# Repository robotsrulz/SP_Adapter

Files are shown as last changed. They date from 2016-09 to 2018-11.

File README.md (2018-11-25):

Logitech G25/G27 pedals/shifter adapter
=======================================

The idea behind this project is to create open and inexpensive USB HID adapter for Logitech G25 / G27 pedals and shifters based on affordable components. Once you bought (or built) your new shiny and awesome direct drive steering wheel you no longer need your old but still working Logitech wheel. But it parts still can be used as standalone device.

I am aware that some shops already sell similar adapters. Unfortunately these devices are quite expensive and not open source. Also I want to practice a bit with STM32 programming :)

Hardware part is based on STM32F042 microcontroller(TSSOP20), Schematics folder contains Gerber files as well as DipTrace source files.

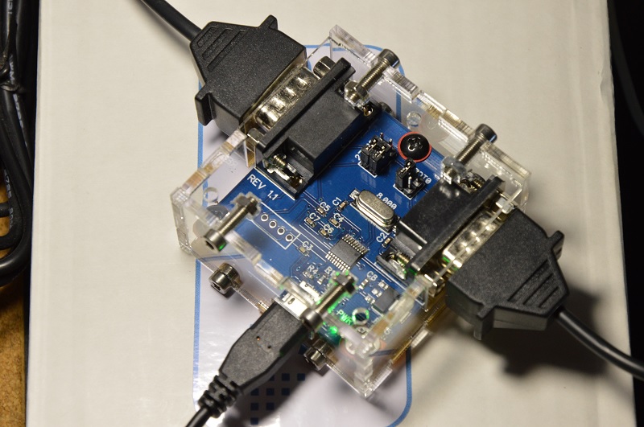
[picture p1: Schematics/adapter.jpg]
Adapter


New firmware for board revisions 1.0 and 1.1 with G25 sequential mode support:

 [hse-2.09a.dfu](binaries/hse-2.09a.dfu) 
 [SP_Profiler](binaries/SP_Profiler_209.exe) 
 
Previous firmware for board revisions 1.0 and 1.1:

 [hse-2.07a.dfu](binaries/hse-2.07a.dfu) 
 [SP_Profiler](binaries/SP_Profiler_1.2.exe) 
 
Firmware for STM32F103C8T6 "Blue Pill" development board:

 [bluepill-2.07.hex](https://github.com/robotsrulz/SP_Adapter/blob/stm32f103c8t6/binaries/bluepill-2.07.hex) 
 [SP_Profiler](binaries/SP_Profiler_1.2.exe) 
 
## Firmware update

1. Disconnect the device and open the case.
2. Place jumper BOOT0 to right position (assuming you're holding the board with USB connector down and DB9 connectors left and right. Normal position of BOOT0 jumper is left side).
3. Install STM DfuSe, download it here: https://goo.gl/JMUFBS (free registration required). Alternatively install it from my Google Drive: https://goo.gl/dp4XGH
4. Connect the board to computer, it should be detected as "STM device in DFU mode"
5. Download firmware .dfu file.
6. Run DfuSe, mark Verify checkbox, press Choose button, select firmware image, then press Upgrade, agree to the warning message.
7. When Progress bar turns blue firmware update is complete, disconnect the board, move jumper BOOT0 back to the left position, close the case, connect it to computer, the board should be detected as "Shifter/Pedals Adapter". Firmware update complete!

Calibration software (Windows x86):

 [SP_Profiler_1.2.exe](binaries/SP_Profiler_1.2.exe)
 
## Calibration procedure

1. Download and run SP_Profiler.exe.
2. The board should be detected as HID-device in the drop down menu, and red cross should be visible in the calibration area.
3. Press Read button, the blue lines should be visible.
4. The idea of shifter calibration is to match actual shifter X an Y potentiometer positions to gear detection zones, see illustration: calibration
You can move blue lines by altering numbers in corresponding edit fields, hit Update button after each edit. Then check if shifter positions are detected correctly. Once you satisfied how shifter detects selected gear press Update and close SP_Profiler, values are stored in adapter flash memory.

## Obtaining the board

PCB is available to order on [kitnic.it](https://kitnic.it/boards/github.com/robotsrulz/SP_Adapter/). I'm testing data for 1clickBOM Chrome plugin to order all parts from major component suppliers (Digikey, Mouser, RS, Newark, Farnell). I'm also selling a small amount of the boards assembled manually by myself, contact me if you want one.

## USB VID/PID

The board uses VID 0x1209 (InterBiometrics) / PID 0xF00D to identify itself, see [pid.codes](http://pid.codes/1209/F00D/) database.

## License

This project is licensed under the BSD License - see the [LICENSE](LICENSE) file for details

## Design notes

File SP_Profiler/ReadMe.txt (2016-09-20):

================================================================================
    БИБЛИОТЕКА MICROSOFT FOUNDATION CLASS. Обзор проекта SP_Profiler
===============================================================================

Это приложение SP_Profiler автоматически создано с помощью мастера приложений. Это приложение демонстрирует основные принципы использования классов Microsoft Foundation; оно также может использоваться в качестве основы для написания собственных приложений.

В этом файле представлена сводка содержимого всех файлов, входящих в состав приложения SP_Profiler.

SP_Profiler.vcxproj
    Это основной файл проекта VC++, создаваемый с помощью мастера приложений. Он содержит данные о версии языка Visual C++, использованной для создания файла, а также сведения о платформах, конфигурациях и функциях проекта, выбранных с помощью мастера приложений.

SP_Profiler.vcxproj.filters
    Это файл фильтров для проектов VC++, созданный с помощью мастера приложений. Он содержит сведения о сопоставлениях между файлами в вашем проекте и фильтрами. Эти сопоставления используются в среде IDE для группировки файлов с одинаковыми расширениями в одном узле (например CPP-файлы сопоставляются с фильтром "Исходные файлы").

SP_Profiler.h
    Это основной файл заголовка приложения.
    Он содержит прочие заголовки, относящиеся к проекту (включая Resource.h), а также объявляет класс приложения CSP_ProfilerApp.

SP_Profiler.cpp
    Это основной исходный файл приложения, в котором содержится класс приложения CSP_ProfilerApp.

SP_Profiler.rc
    Он представляет собой список всех ресурсов Microsoft Windows, используемых программой. В него включены значки, точечные рисунки и курсоры, хранящиеся в подкаталоге RES. Этот файл можно редактировать непосредственно в Microsoft Visual C++. Ресурсы проекта находятся в 1049.

res\SP_Profiler.ico
    Файл значка, используемый в качестве значка приложения. Этот значок включен с помощью основного файла ресурсов SP_Profiler.rc.

res\SP_Profiler.rc2
    Этот файл содержит ресурсы, которые нельзя редактировать в Microsoft Visual C++. В этот файл следует поместить все ресурсы, не редактируемые редактором ресурсов.

/////////////////////////////////////////////////////////////////////////////

Мастер приложений создает один класс диалогового окна:

SP_ProfilerDlg.h, SP_ProfilerDlg.cpp — диалоговое окно
    Эти файлы содержат класс CSP_ProfilerDlg. Этот класс определяет поведение главного диалогового окна приложения. Шаблон диалогового окна находится в файле SP_Profiler.rc, который можно изменять с помощью Microsoft Visual C++.

/////////////////////////////////////////////////////////////////////////////

Другие стандартные файлы:

StdAfx.h, StdAfx.cpp
    Эти файлы используются для построения файла предкомпилированного заголовка (PCH) с именем SP_Profiler.pch и файла предкомпилированных типов с именем StdAfx.obj.

Resource.h
    Это стандартный файл заголовка, в котором определяются новые идентификаторы ресурсов. Такой файл можно прочитать и обновить в Microsoft Visual C++.

SP_Profiler.manifest
	Файлы манифеста приложения используются операционной системой Windows XP для описания зависимости приложений от определенных версий параллельных сборок. Эти сведения используются загрузчиком для загрузки соответствующей сборки из кэша сборок или частным образом из приложения. Манифест приложения можно включить для распространения в качестве внешнего MANIFEST-файла, устанавливаемого в одной папке с исполняемым файлом приложения, или внедрить в исполняемый файл в виде ресурса.
/////////////////////////////////////////////////////////////////////////////

Прочие примечания.

С помощью комментариев «TODO:» в мастере приложений обозначаются фрагменты исходного кода, которые необходимо дополнить или изменить.

Если приложение использует MFC в общей библиотеке DLL, необходимо обеспечить распространение библиотек DLL MFC. Если в приложении используется язык, отличный от языка операционной системы, потребуется также обеспечить распространение соответствующих локализованных ресурсов mfc110XXX.DLL.
Дополнительные сведения о выполнении этих задач см. в разделе документации MSDN, посвященном распространению приложений Visual C++.

/////////////////////////////////////////////////////////////////////////////

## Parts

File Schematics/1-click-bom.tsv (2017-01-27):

References | Qty | Description | Manufacturer | MPN | Digikey | Mouser | RS | Newark | Farnell
25/27 | 1 |  |  | 90131-0123 | WM8121-ND | 538901310123 | 6703443 | 60H4442 | 2381222
BOOT0 | 1 |  |  | 90131-0122 | WM8120-ND | 538901310122 | 6703449 | 25M5898 | 1756986
C1-C2 | 2 | 22pF,0603 |  | C0603C220J1GACTU | 399-7874-2-ND | 80C0603C220J1G | 8015350 | 75R1532 | 1813429
C3-C4 | 2 | 100nF,0603 |  | C0603C104K5RACTU | 399-5089-2-ND | 80C0603C104K5R | 8015347 | 72J5992 | 1692286
C5 | 1 | 4.7uF,0603 |  | CL10A475KL8NRNC | 1276-6794-6-ND | 81GRM188R60J475ME9D | 6911155 | 62W5999 | 2211163
C6 | 1 | 10nF,0603 |  | C0603C103J5JAC7867 | 399-13384-1-ND | 810C1608X7R1H103K | 7882988 | 45Y5166 | 2470427
C7 | 1 | 1uF,0603 |  | GRM188R61H105KAALD | 490-10732-6-ND | 81GRM188R61H105KALD | 8467300 | 13T1194 | 1845736
C8 | 1 | 10uF,0603 |  | GRM188R6YA106MA73D | 490-13248-6-ND | 81GRM188R6YA106MA3D | 8151345 | 45Y5222 | 2470486
HC49SMD | 1 | 8.000 |  | AT-8.000MAGK-T | 887-1599-6-ND | 717AT8.000MAGKT | 6720340 | 76Y3930 | 2142539
LM1117-3.3 | 1 | REG1117-3.3 |  | LM1117MPX-3.3/NOPB | LM1117MPX-3.3/NOPBCT-ND | 926LM1117MPX3.3NOPB | 5358635 | 41K3450 | 1469051
PEDALS | 1 |  |  | 788750-1 | 788750-1-ND | 66720TQC47MYF | 1217389 | 01M3123 | 2294289
R1-R2 | 2 | 22R,0603 |  | RC0603JR-0722RL | 311-22GRCT-ND | 603RC0603JR0722RL | 8323168 | 68R0168 | 9233172
R3 | 1 | 100k,0603 |  | RC0603JR-07100KL | 311-100KGRCT-ND | 603RC0603JR07100KL | 6789673 | 68R0147 | 9233628
R4 | 1 | 4.7k 0603 |  | RC0603JR-074K7L | 311-4.7KGRCT-ND | 603RC0603JR0747KL | 7408877 | 68R0188 | 9233466
R5 | 1 | 360R 0603 |  | RC0603JR-07360RL | 311-360GRCT-ND | 603RC0603JR07360RL |  | 66R2746
PWR | 1 | LED 0603 |  | Q396-PS-35 | LG Q396-PS-35-ND | 720LGQ396A3964 |  | 86Y0826 | 2575345
SHIFTER | 1 |  |  | 787203-3 | A32089-ND | 57157472506 | 7981072 | 42K8789 | 1087695
ST-LINK | 1 |  |  | 640453-5 | A19341-ND | 5716404535 | 8640754 | 22C6367 | 588672
STM32F042F6P6 | 1 |  |  | STM32F042F6P | STM32F042F6P6-ND | 511STM32F042F6P6 | 8607501 | 42Y1015 | 2469549
USBMicroB | 1 |  |  | ZX62-B-5PA | H125270CT-ND | 798ZX62B5PA33 | 6850965 | 86P8793 | 1645325

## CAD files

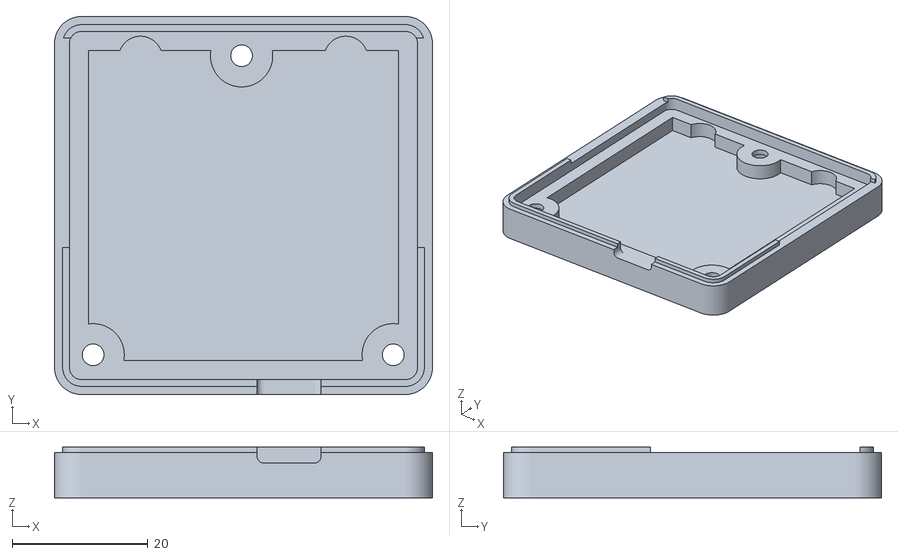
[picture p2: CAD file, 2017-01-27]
Schematics/Case_Bottom.stl
55.8 x 55.8 x 7.50

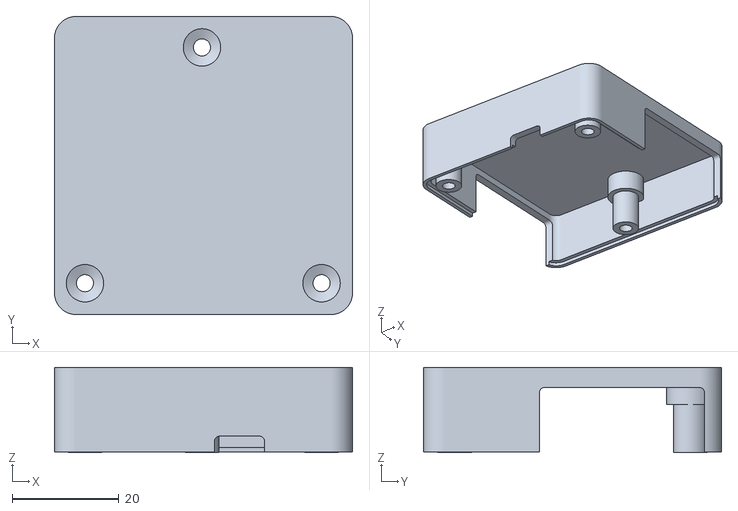
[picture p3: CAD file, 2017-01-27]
Schematics/Case_Top.stl
55.8 x 55.8 x 16.0

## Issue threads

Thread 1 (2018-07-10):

Files missing for kitspace.org

kasbah, 2018-07-10:
Hello, Gerbers and BOM are now missing for the [kitspace.org page](https://kitspace.org/boards/github.com/robotsrulz/sp_adapter/). I have locked it down to 0391e520c2f1e953f703b467ebe6b8022971771 for now. What's the plan for the kitspace.org page?

robotsrulz, 2018-07-10:
Please remove my page from kitspace.org, I am no longer interested in being listed. Thank you for your efforts!

kasbah, 2018-07-10:
I can do this as soon as I am back on my laptop. Can I ask why you no
longer want it to be listed? What would Kitspace need for you to put this
and future projects there?

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

robotsrulz, 2018-07-10:
I see no benefit from being listed but I have to maintain all the files in
actual state. It's like manually registering in a search engine that is not
widely used. And I don't feel like somebody needs details about the
project. People I'm usually talking with are only interested in complete
and working solution, not details under the hood.

вт, 10 июл. 2018 г. в 22:38, Kaspar Emanuel <notifications@github.com>:

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

kasbah, 2018-07-10:
That's a shame. Do you mind leaving up the old version as it is for now?
Maybe as I add features and if Kitspace manages to get more popular you
will see more benefit.

Part of the plan is to reduce the maintenance burden by extracting all the
info from the files you use yourself. Once that happens it should be easy
to bring up to date.

I have seen some people clicking through and ordering PCBs for this on the
analytics by the way. Maybe it would be nice to integrate click counts that
everyone can see on the links.

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

robotsrulz, 2018-07-10:
I don't mind if you leave the old version however it's up to you.

There is a page on SeeedStudio site offering me 10% from each PCB order and I never received any money from them so I don't care any more. However people ask me about complete boards so I will focus on this now.

kasbah, 2018-07-10:
Cool, I'll leave it up at that version for now. Let me know if you ever change your mind.

It makes sense that people prefer a finished product but I thought you would have heard of at least a few people DIYing it. Even if you do get some, I think making money through referrals to the PCB fabs is much more of a challenge. I know because that's how I am trying to make money for Kitspace development and it's not making very much.

Maybe the future for Kitspace could be in assisting people to get to the finished product and selling that through registering group buys. It could still serve people that want to DIY more niche projects but as you are experiencing, when you have a known working, popular design then most people will just want to have the full solution rather than having to make it themselves.

I am wondering how you are finding the process of doing these smaller runs and selling them. What are the hardest challenges and what are annoying little things that you feel like should be solved already?

I know finding buyers is always a challenge and I wish Kitspace was in more of a state to help there. Maybe one day.

Closed 2018-07-10.

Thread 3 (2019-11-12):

Load cell/pressure sensor compatability

Frozennortherner, 2019-11-12:
Hi, I wondered if it is at all possible for a native load cell/pressure sensor support for this? I bought a board from ebay with the hope that my "perfect pedal"  G27 brake mod would work with it, but no dice... :(
It does however work with the G27 wheel itself

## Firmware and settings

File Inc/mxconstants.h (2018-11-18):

/**
  ******************************************************************************
  * File Name          : mxconstants.h
  * Description        : This file contains the common defines of the application
  ******************************************************************************
  *
  * COPYRIGHT(c) 2016 STMicroelectronics
  *
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
  ******************************************************************************
  */
/* Define to prevent recursive inclusion -------------------------------------*/
#ifndef __MXCONSTANT_H

#define SHIFTER_X_Pin GPIO_PIN_0
#define SHIFTER_X_GPIO_Port GPIOA
#define SHIFTER_Y_Pin GPIO_PIN_1
#define SHIFTER_Y_GPIO_Port GPIOA
#define THROTTLE_Pin GPIO_PIN_2
#define THROTTLE_GPIO_Port GPIOA
#define BRAKE_Pin GPIO_PIN_3
#define BRAKE_GPIO_Port GPIOA
#define CLUTCH_Pin GPIO_PIN_4
#define CLUTCH_GPIO_Port GPIOA
#define SPI1_nCS_Pin GPIO_PIN_1
#define SPI1_nCS_GPIO_Port GPIOB

#endif /* __MXCONSTANT_H */

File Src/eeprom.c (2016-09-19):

/**
  ******************************************************************************
  * @file    EEPROM_Emulation/src/eeprom.c 
  * @author  MCD Application Team
  * @version V1.6.0
  * @date    27-May-2016
  * @brief   This file provides all the EEPROM emulation firmware functions.
  ******************************************************************************
  * @attention
  *
  * <h2><center>&copy; COPYRIGHT(c) 2016 STMicroelectronics</center></h2>
  *
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
  ******************************************************************************
  */ 

/** @addtogroup EEPROM_Emulation
  * @{
  */ 

/* Includes ------------------------------------------------------------------*/
#include "eeprom.h"

/* Private typedef -----------------------------------------------------------*/
/* Private define ------------------------------------------------------------*/
/* Private macro -------------------------------------------------------------*/
/* Private variables ---------------------------------------------------------*/

/* Global variable used to store variable value in read sequence */
uint16_t DataVar = 0;

/* Virtual address defined by the user: 0xFFFF value is prohibited */
extern uint16_t VirtAddVarTab[NB_OF_VAR];

/* Private function prototypes -----------------------------------------------*/
/* Private functions ---------------------------------------------------------*/
static HAL_StatusTypeDef EE_Format(void);
static uint16_t EE_FindValidPage(uint8_t Operation);
static uint16_t EE_VerifyPageFullWriteVariable(uint16_t VirtAddress, uint16_t Data);
static uint16_t EE_PageTransfer(uint16_t VirtAddress, uint16_t Data);
static uint16_t EE_VerifyPageFullyErased(uint32_t Address);

/**
  * @brief  Restore the pages to a known good state in case of page's status
  *   corruption after a power loss.
  * @param  None.
  * @retval - Flash error code: on write Flash error
  *         - FLASH_COMPLETE: on success
  */
uint16_t EE_Init(void)
{
  uint16_t pagestatus0 = 6, pagestatus1 = 6;
  uint16_t varidx = 0;
  uint16_t eepromstatus = 0, readstatus = 0;
  int16_t x = -1;
  HAL_StatusTypeDef  flashstatus;
  uint32_t page_error = 0;
  FLASH_EraseInitTypeDef s_eraseinit;


  /* Get Page0 status */
  pagestatus0 = (*(__IO uint16_t*)PAGE0_BASE_ADDRESS);
  /* Get Page1 status */
  pagestatus1 = (*(__IO uint16_t*)PAGE1_BASE_ADDRESS);

  /* Fill EraseInit structure*/
  s_eraseinit.TypeErase   = FLASH_TYPEERASE_PAGES;
  s_eraseinit.PageAddress = PAGE0_BASE_ADDRESS;
  s_eraseinit.NbPages     = 1;
  
  /* Check for invalid header states and repair if necessary */
  switch (pagestatus0)
  {
    case ERASED:
      if (pagestatus1 == VALID_PAGE) /* Page0 erased, Page1 valid */
      {
          /* Erase Page0 */
        if(!EE_VerifyPageFullyErased(PAGE0_BASE_ADDRESS))
        {
          flashstatus = HAL_FLASHEx_Erase(&s_eraseinit, &page_error);
          /* If erase operation was failed, a Flash error code is returned */
          if (flashstatus != HAL_OK)
          {
            return flashstatus;
          }
        }
      }
      else if (pagestatus1 == RECEIVE_DATA) /* Page0 erased, Page1 receive */
      {
        /* Erase Page0 */
        if(!EE_VerifyPageFullyErased(PAGE0_BASE_ADDRESS))
        { 
          flashstatus = HAL_FLASHEx_Erase(&s_eraseinit, &page_error);
          /* If erase operation was failed, a Flash error code is returned */
          if (flashstatus != HAL_OK)
          {
            return flashstatus;
          }
        }
        /* Mark Page1 as valid */
        flashstatus = HAL_FLASH_Program(FLASH_TYPEPROGRAM_HALFWORD, PAGE1_BASE_ADDRESS, VALID_PAGE);
        /* If program operation was failed, a Flash error code is returned */
        if (flashstatus != HAL_OK)
        {
          return flashstatus;
        }
      }
      else /* First EEPROM access (Page0&1 are erased) or invalid state -> format EEPROM */
      {
        /* Erase both Page0 and Page1 and set Page0 as valid page */
        flashstatus = EE_Format();
        /* If erase/program operation was failed, a Flash error code is returned */
        if (flashstatus != HAL_OK)
        {
          return flashstatus;
        }
      }
      break;
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

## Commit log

2016-08-04 initial checkin
    [BoardOutline.gbr, Bottom.gbr, BottomMask.gbr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]
2016-08-05 ported some code from stm32f103c8t6, need real mcu to check
2016-08-18 added nessesary files for http://kitnic.it
    kitnic.yaml and 1-click-bom.tsv
    [1-click-bom.tsv]
2016-08-18 Fixed 1-click-bom.tsv
    [1-click-bom.tsv]
2016-08-18 Fixed some BOM glitches, added link to kitnic.it
    [1-click-bom.tsv]
2016-08-22 simple case for the adapter
    [Case_Bottom.stl, Case_Top.stl]
2016-08-24 changed usb VID/PID to 0x1209/0xF00D
    Since InterBiometrics shared their VID to OSHW community one can use
    their PIDs for open hardware projects, see http://pid.codes/howto/ for
    details.
2016-08-28 switched from HSE to HSI48
    HSE doesn't work for some reason
2016-08-28 longer adc sampling time, thresholds adjusted
2016-09-02 updated stl files for the case, added TODO list
    [Case_Bottom.stl, Case_Top.stl]
2016-09-05 case fixes
    [Case_Bottom.stl, Case_Top.stl]
2016-09-16 added x and y axis
2016-09-18 preliminary support for calibration
2016-09-25 added simple complementary filter
2016-09-26 gear selection fix
2016-09-29 x, y axis mute for calibration or
    Press simultaneously left red button, right red button and d-pad up to
    lock x and y axis.
    Press simultaneously left red button, right red button and d-pad up to
    unlock
2016-10-04 reworked pcb (DipTrace only, Gerbers not updated), added power led + mounting holes
    suitable for acrylic case + standoffs
    [motherboard_stand.STP]
2016-10-04 masked x and y axis, version is set to 2.06 (don't ask)
2016-10-06 Acrylic case for adapter pcb ver 1.1
    [Case-1.1.dxf]
2016-10-27 2.07 untested - more aggressive spi timings
2017-01-27 Board revision 1.1 - cleanups
    [1-click-bom.tsv, Case-1.1.dxf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]
2017-01-27 Board revision 1.1 - case update
    [Case_Bottom.stl, Case_Top.stl]
2017-01-27 Board revision 1.1 - image update
2017-02-28 preliminary support for board revision 1.2
2017-03-19 board rev 1.2 fixes & trying to make autodetect
2017-03-20 added shottky diode
2017-04-05 HID descriptors for board v1.2
2017-06-09 Profiler update for board rev 1.2, removed old files
2018-07-10 removed obsolete stuff
    [1-click-bom.tsv, Case_Bottom.stl, Case_Top.stl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]
2018-07-10 begin firmware rework for 1.4
    [mxconstants.h]

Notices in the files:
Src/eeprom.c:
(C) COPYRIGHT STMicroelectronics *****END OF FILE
